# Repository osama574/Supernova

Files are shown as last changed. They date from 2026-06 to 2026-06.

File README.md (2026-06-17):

# Supernova ESP32 Smart Display

Supernova is a two-device ESP32 smart display project:

- `esp32-touchscreen`: LVGL touchscreen firmware for a diymore/LCDWiki 4.0 inch ESP32-32E display.
- `esp32-camera`: ESP32-CAM firmware for an AI-Thinker style ESP32-CAM with OV2640.
- `node-red`: Node-RED flow for simple MQTT motor control from a laptop dashboard.

The touchscreen is the main UI. It shows the Supernova boot animation, home dashboard, WiFi/settings, music, weather, clock, calendar, calculator, timer, and motor control. The camera firmware can join the same WiFi network, announce its IP to the display, and expose HTTP camera endpoints. Node-RED can send MQTT commands to move the two servos.

## Hardware

### Touchscreen firmware

Folder:

```text
esp32-touchscreen
```

Intended device:

- diymore / LCDWiki 4.0 inch ESP32-32E display
- 320 x 480 LCD, used in landscape as 480 x 320
- ST7796S display over SPI
- XPT2046 resistive touch over SPI
- LVGL 9 based UI

Connected extras used by the firmware:

- MAX98357A I2S audio amplifier and speaker
- microSD card for WAV music files
- WS2812/NeoPixel style LED ring
- Two servo motors for pan/tilt control

Hardware notes are in:

```text
esp32-touchscreen/docs/supernova_hardware_wiring.md
```

### Camera firmware

Folder:

```text
esp32-camera
```

Intended device:

- ESP32-CAM / AI-Thinker style module
- OV2640 camera
- PSRAM enabled board profile through PlatformIO `esp32cam`

The camera firmware provides:

- WiFi connection
- ESP-NOW credential receiving from the touchscreen
- HTTP status and camera endpoints
- Camera IP announcement back to the touchscreen

Useful endpoints after the ESP32-CAM is connected:

```text
http://CAMERA_IP/status
http://CAMERA_IP/capture
http://CAMERA_IP/stream
```

## Required Software

- VS Code with PlatformIO extension, or PlatformIO CLI
- Arduino framework through PlatformIO
- Node-RED already installed, if you want the laptop motor dashboard
- MQTT broker on the laptop, for example Mosquitto

## Configuration To Change

Before publishing or flashing your own copy, check these values.

### WiFi defaults

The GitHub copy uses placeholders so real WiFi credentials are not published.

Touchscreen:

```text
esp32-touchscreen/src/supernova_state.cpp
```

Camera:

```text
esp32-camera/src/main.cpp
```

Change:

```cpp
static const char * default_wifi_ssid = "CHANGE_ME_WIFI_SSID";
static const char * default_wifi_password = "CHANGE_ME_WIFI_PASSWORD";
```

The touchscreen also lets you connect to WiFi from the Settings UI. Successful WiFi credentials are saved in ESP32 flash. The ESP32-CAM can also receive WiFi credentials from the touchscreen over ESP-NOW.

If a device already has old saved credentials, use the touchscreen WiFi UI to connect to the new network, or erase flash from PlatformIO.

### MQTT broker IP

The ESP32 touchscreen must connect to the laptop's network IP address, not `localhost`.

Change this in:

```text
esp32-touchscreen/platformio.ini
```

Example:

```ini
-DSUPERNOVA_MQTT_HOST=\"172.20.10.2\"
```

If your laptop IP changes, update this value and upload the touchscreen firmware again.

Node-RED can use `127.0.0.1` if Node-RED and the MQTT broker are on the same laptop. If the broker is on another computer, change the broker in the Node-RED MQTT config node.

### Serial ports

The upload ports are examples and may be different on your computer:

- Touchscreen was tested on `COM6`
- ESP32-CAM was tested on `COM4`

Check Windows Device Manager or PlatformIO devices if your ports differ.

## Build And Upload: Touchscreen

From PowerShell:

```powershell
cd "C:\path\to\Supernova-ESP32-GitHub\esp32-touchscreen"
pio run -e esp32_32e_display
pio run -e esp32_32e_display -t upload --upload-port COM6
```

Serial monitor:

```powershell
pio device monitor -e esp32_32e_display --port COM6
```

If `pio` is not found but PlatformIO is installed by VS Code, use:

```powershell
& "$env:USERPROFILE\.platformio\penv\Scripts\pio.exe" run -e esp32_32e_display
```

## Build And Upload: ESP32-CAM

From PowerShell:

```powershell
cd "C:\path\to\Supernova-ESP32-GitHub\esp32-camera"
pio run -e esp32cam_ai_thinker
pio run -e esp32cam_ai_thinker -t upload --upload-port COM4
```

Serial monitor:

```powershell
pio device monitor -e esp32cam_ai_thinker --port COM4
```

If uploading fails, put the ESP32-CAM in bootloader mode. On many ESP32-CAM-MB adapter boards this means holding the `IO0` button, pressing reset, then starting upload. Release `IO0` after upload starts.

## Node-RED Motor Control

Flow file:

```text
node-red/nodered-supernova-motors-flow.json
```

Import:

1. Open Node-RED.
2. Menu -> Import.
3. Select the JSON file above or paste its contents.
4. Deploy.
5. Open the Node-RED dashboard.

The flow publishes servo commands to:

```text
supernova/motors/cmd
```

Payloads:

```text
up
down
left
right
```

The touchscreen publishes servo state to:

```text
supernova/motors/state
```

Example Mosquitto config:

```text
node-red/mosquitto-supernova.conf
```

For the ESP32 to reach the broker, Mosquitto must listen on the laptop network interface, not only on `localhost`. The included config uses:

```conf
listener 1883 0.0.0.0
allow_anonymous true
```

You may also need to allow port `1883` in Windows Firewall.

## Music Files

Put music files on the touchscreen SD card in:

```text
/music
```

The current firmware is focused on WAV playback. Use FAT32 for the SD card.

## Repository Layout

```text
Supernova-ESP32-GitHub/
  README.md
  .gitignore
  esp32-touchscreen/
    platformio.ini
    include/
    lib/
    scripts/
    src/
    docs/
  esp32-camera/
    platformio.ini
    src/
  node-red/
    nodered-supernova-motors-flow.json
    mosquitto-supernova.conf
```

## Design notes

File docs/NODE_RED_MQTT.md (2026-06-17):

# Node-RED And MQTT Motor Control

The Node-RED dashboard controls the same pan/tilt servos as the touchscreen Motor app.

## Files

Node-RED flow:

```text
node-red/nodered-supernova-motors-flow.json
```

Example Mosquitto config:

```text
node-red/mosquitto-supernova.conf
```

## MQTT Broker

The MQTT broker must run on the laptop or another computer reachable by the ESP32 touchscreen.

The included Mosquitto config:

```conf
listener 1883 0.0.0.0
allow_anonymous true
persistence false
log_type all
```

Why this matters:

- Node-RED can connect to `127.0.0.1` if it runs on the same laptop as the broker.
- The ESP32 cannot use `localhost`; it must use the laptop network IP address.

Example:

```text
Laptop MQTT broker IP: 172.20.10.2
MQTT port: 1883
```

Then set this in:

```text
esp32-touchscreen/platformio.ini
```

```ini
-DSUPERNOVA_MQTT_HOST=\"172.20.10.2\"
```

Rebuild and upload the touchscreen firmware after changing this value.

## Import Node-RED Flow

1. Open Node-RED.
2. Open the menu.
3. Choose Import.
4. Select `node-red/nodered-supernova-motors-flow.json`, or paste its contents.
5. Import the flow.
6. Deploy.
7. Open the Node-RED dashboard.

The flow contains:

- Up button
- Down button
- Left button
- Right button
- MQTT output node
- MQTT input node for servo state
- Text display for the latest servo state

## MQTT Topics

Command topic:

```text
supernova/motors/cmd
```

Accepted payloads:

```text
up
down
left
right
```

State topic:

```text
supernova/motors/state
```

Example state payload:

```json
{"pan":135,"tilt":135,"source":"status"}
```

## Test Broker From Windows

Check local broker:

```powershell
Test-NetConnection 127.0.0.1 -Port 1883
```

Check broker on laptop network IP:

```powershell
Test-NetConnection 172.20.10.2 -Port 1883
```

Both should show:

```text
TcpTestSucceeded : True
```

If `127.0.0.1` works but the laptop IP does not, the broker is only listening locally or Windows Firewall is blocking port 1883.

## Windows Firewall

If needed, allow MQTT inbound traffic:

```powershell
New-NetFirewallRule -DisplayName "MQTT 1883" -Direction Inbound -Protocol TCP -LocalPort 1883 -Action Allow
```

Run PowerShell as Administrator for this command.

## Expected ESP32 Display Status

Open the Motor app on the touchscreen. It should show:

```text
Broker: YOUR_BROKER_IP
MQTT: online
```

If it shows `MQTT: retry`, check:

- Touchscreen WiFi is connected.
- Laptop and touchscreen are on the same network.
- MQTT broker is running.
- `SUPERNOVA_MQTT_HOST` is the laptop IP.
- Windows Firewall allows port 1883.

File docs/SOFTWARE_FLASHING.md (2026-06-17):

# Software Setup And Flashing

This repository contains two separate PlatformIO projects.

| Folder | Device | PlatformIO Environment |
| --- | --- | --- |
| `esp32-touchscreen` | diymore/LCDWiki 4.0 inch ESP32-32E touchscreen | `esp32_32e_display` |
| `esp32-camera` | ESP32-CAM AI-Thinker style board | `esp32cam_ai_thinker` |

## Install Requirements

Required:

- VS Code
- PlatformIO extension for VS Code, or PlatformIO CLI
- USB cable for the touchscreen
- USB programmer/adapter for the ESP32-CAM

If `pio` is not available in PowerShell, use the VS Code PlatformIO terminal or this full path:

```powershell
& "$env:USERPROFILE\.platformio\penv\Scripts\pio.exe"
```

## Configure WiFi

The GitHub copy uses placeholders.

Touchscreen file:

```text
esp32-touchscreen/src/supernova_state.cpp
```

Camera file:

```text
esp32-camera/src/main.cpp
```

Change:

```cpp
static const char * default_wifi_ssid = "CHANGE_ME_WIFI_SSID";
static const char * default_wifi_password = "CHANGE_ME_WIFI_PASSWORD";
```

The touchscreen can also change WiFi from the Settings app. Successful WiFi credentials are saved in ESP32 flash.

## Configure MQTT Broker IP

The touchscreen connects directly to the MQTT broker. If the broker runs on your laptop, use the laptop IP address on the same WiFi network.

Edit:

```text
esp32-touchscreen/platformio.ini
```

Change:

```ini
-DSUPERNOVA_MQTT_HOST=\"CHANGE_ME_BROKER_IP\"
```

Example:

```ini
-DSUPERNOVA_MQTT_HOST=\"172.20.10.2\"
```

Do not use `localhost` for the ESP32. On the ESP32, `localhost` means the ESP32 itself, not the laptop.

## Build Touchscreen Firmware

PowerShell:

```powershell
cd "C:\path\to\Supernova\esp32-touchscreen"
pio run -e esp32_32e_display
```

If `pio` is not found:

```powershell
cd "C:\path\to\Supernova\esp32-touchscreen"
& "$env:USERPROFILE\.platformio\penv\Scripts\pio.exe" run -e esp32_32e_display
```

Expected result:

```text
[SUCCESS]
```

## Upload Touchscreen Firmware

Find the COM port in Windows Device Manager or PlatformIO devices. Example port:

```text
COM6
```

Upload:

```powershell
cd "C:\path\to\Supernova\esp32-touchscreen"
pio run -e esp32_32e_display -t upload --upload-port COM6
```

Serial monitor:

```powershell
pio device monitor -e esp32_32e_display --port COM6
```

Expected after boot:

- Supernova boot animation
- Home dashboard
- Touch works in landscape

## Build ESP32-CAM Firmware

PowerShell:

```powershell
cd "C:\path\to\Supernova\esp32-camera"
pio run -e esp32cam_ai_thinker
```

Expected result:

```text
[SUCCESS]
```

## Upload ESP32-CAM Firmware

Example port:

```text
COM4
```

Upload:

```powershell
cd "C:\path\to\Supernova\esp32-camera"
pio run -e esp32cam_ai_thinker -t upload --upload-port COM4
```

Serial monitor:

```powershell
pio device monitor -e esp32cam_ai_thinker --port COM4
```

ESP32-CAM bootloader mode:

- If upload does not start, hold `IO0`.
- Press `RST`.
- Start upload.
- Release `IO0` after upload begins.

Some ESP32-CAM-MB boards have an `IO0` button instead of requiring a jumper.

## Erase Flash

Erase flash if old WiFi credentials or settings are stuck:

Touchscreen:

```powershell
cd "C:\path\to\Supernova\esp32-touchscreen"
pio run -e esp32_32e_display -t erase --upload-port COM6
```

Camera:

```powershell
cd "C:\path\to\Supernova\esp32-camera"
pio run -e esp32cam_ai_thinker -t erase --upload-port COM4
```

Then upload firmware again.

## What The Firmware Does

Touchscreen firmware:

- Initializes ST7796S LCD in landscape
- Initializes XPT2046 touch
- Runs LVGL 9 UI
- Shows Supernova boot animation
- Provides dashboard apps
- Saves theme/language/brightness/WiFi settings
- Reads WAV music from SD card
- Controls two servo motors
- Controls LED ring
- Receives camera IP state
- Subscribes to MQTT motor commands

Camera firmware:

- Initializes OV2640 camera
- Connects to WiFi
- Receives WiFi credentials over ESP-NOW
- Starts HTTP camera server
- Announces IP address to touchscreen

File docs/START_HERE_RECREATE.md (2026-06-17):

# Start Here: Recreate The Supernova Project

This document is the handoff guide for rebuilding Supernova from the repository with no extra help. Follow the sections in order.

## What You Are Building

Supernova is a smart display system made from two ESP32 devices:

1. Main display controller
   - diymore/LCDWiki 4.0 inch ESP32-32E touchscreen display
   - Runs the LVGL user interface
   - Controls music, settings, WiFi, weather, clock, calendar, timer, calculator, servos, LED ring, and MQTT motor commands

2. Camera controller
   - ESP32-CAM AI-Thinker style board with OV2640 camera
   - Joins the same WiFi network
   - Provides HTTP camera endpoints
   - Announces its IP address to the touchscreen

There is also a Node-RED dashboard flow for controlling the servo motors over MQTT from a laptop.

## Repository Map

```text
Supernova/
  README.md
  docs/
    START_HERE_RECREATE.md
    BOM.md
    3D_PRINTING_AND_ASSEMBLY.md
    WIRING.md
    SOFTWARE_FLASHING.md
    NODE_RED_MQTT.md
    OPERATION_TEST_PLAN.md
    TROUBLESHOOTING.md
  3D-Model/
    pantilt_floor_nolegs.stl
    pantilt_leg.stl
    pantilt_screenpanel.stl
  esp32-touchscreen/
    platformio.ini
    src/
    include/
    scripts/
  esp32-camera/
    platformio.ini
    src/
  node-red/
    nodered-supernova-motors-flow.json
    mosquitto-supernova.conf
```

## Build Order

1. Read `docs/BOM.md` and confirm all parts are available.
2. Print the case parts from `3D-Model/`; follow `docs/3D_PRINTING_AND_ASSEMBLY.md`.
3. Wire the electronics according to `docs/WIRING.md`.
4. Edit WiFi and MQTT settings as described in `docs/SOFTWARE_FLASHING.md`.
5. Build and upload the touchscreen firmware.
6. Build and upload the ESP32-CAM firmware.
7. Import the Node-RED flow using `docs/NODE_RED_MQTT.md`.
8. Run the acceptance test in `docs/OPERATION_TEST_PLAN.md`.
9. If something fails, use `docs/TROUBLESHOOTING.md`.

## Expected Result

After everything is working:

- The touchscreen boots into the Supernova animation and home dashboard.
- Touch works in landscape orientation.
- Settings can connect/disconnect WiFi.
- Music lists WAV files from the SD card.
- The Motor app moves pan/tilt servos from touch buttons.
- The Motor app shows the ESP32-CAM IP when the camera is available.
- Node-RED can move the same motors by publishing MQTT commands.
- The ESP32-CAM exposes camera endpoints on the local network.

## Important Safety Rules

- Do not power the 20 kg servos from the ESP32 display board.
- Do not power the LED ring from the ESP32 display board.
- Use a separate high-current 5V supply for LEDs.
- Use a separate high-current servo supply/BEC for servos.
- Connect all grounds together: ESP32 GND, LED GND, servo supply GND, and audio GND.
- Check polarity before powering the system.
- If a servo moves randomly, remove servo power first, then debug wiring and ground.

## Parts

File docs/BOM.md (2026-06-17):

# Bill Of Materials

This is the hardware needed to recreate the current Supernova prototype.

## Required Electronics

| Qty | Part | Purpose | Notes |
| --- | --- | --- | --- |
| 1 | diymore/LCDWiki 4.0 inch ESP32-32E touchscreen display | Main UI controller | 320 x 480 display, used in landscape as 480 x 320 |
| 1 | ESP32-CAM AI-Thinker style board with OV2640 | Camera controller | Tested with ESP32-CAM-MB style USB programmer |
| 2 | RDS3218 20 kg 270 degree servos | Pan/tilt movement | Needs external servo power |
| 1 | 109 pixel WS2812/NeoPixel compatible LED ring | Addressable LED effect | Needs external 5V power |
| 1 | microSD card | Music storage | FAT32, `/music` folder |
| 1 | Speaker or speaker module supported by the display board | Audio output | Current firmware uses ESP32 DAC output on GPIO26 |
| 1 | Laptop | PlatformIO upload, Node-RED, MQTT broker | Windows commands are documented |

## Optional Electronics

| Qty | Part | Purpose | Notes |
| --- | --- | --- | --- |
| 1 or 2 | MAX98357A amplifier modules | External audio amplifier option | Current firmware does not drive external I2S MAX98357A. Code changes are needed for this option. |
| 1 | PCA9685 servo driver | Cleaner multi-servo control | Recommended future upgrade if more PWM outputs are needed. |

## Power Supplies

| Supply | Recommended Rating | Used For |
| --- | --- | --- |
| USB-C or 5V supply for touchscreen | Stable 5V, at least 1A | ESP32 display board |
| LED supply | 5V, up to 8A for full brightness | 109 LED ring |
| Servo supply/BEC | Match servo rating, several amps per servo | Two high-current servos |

The LED and servo supplies can draw far more current than the ESP32 board can provide. Keep power separate, but connect grounds together.

## Mechanical Parts

Print these files from the repository:

| File | Purpose |
| --- | --- |
| `3D-Model/pantilt_floor_nolegs.stl` | Base/floor part |
| `3D-Model/pantilt_leg.stl` | Leg/support part |
| `3D-Model/pantilt_screenpanel.stl` | Screen panel mount |

See `docs/3D_PRINTING_AND_ASSEMBLY.md` for print and assembly steps.

## Tools

- 3D printer
- Slicer software
- Small screwdrivers
- Soldering iron or reliable Dupont/JST wiring
- Multimeter
- USB cables for both ESP32 devices
- Heat shrink or insulation tape
- Computer with VS Code and PlatformIO

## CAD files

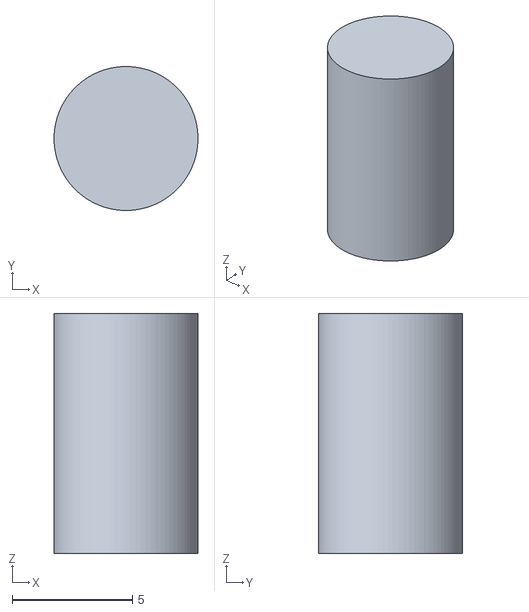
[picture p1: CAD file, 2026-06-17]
3D-Model/pantilt_leg.stl
6.00 x 6.00 x 10.0

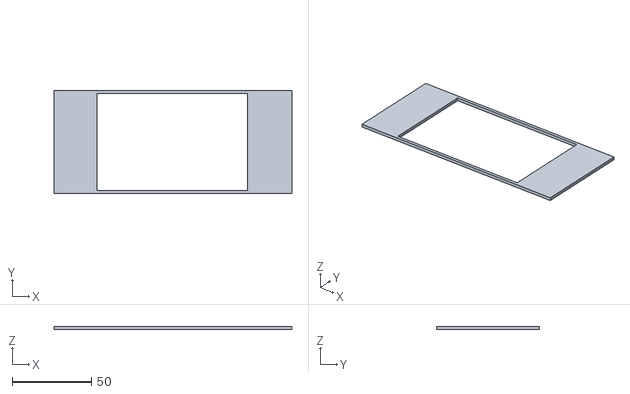
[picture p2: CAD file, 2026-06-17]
3D-Model/pantilt_screenpanel.stl
150.0 x 65.0 x 2.00

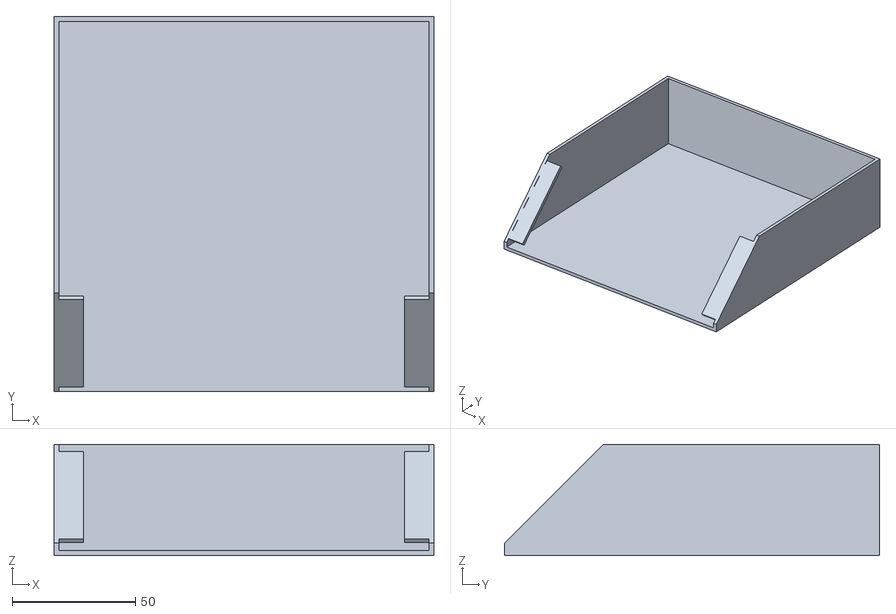
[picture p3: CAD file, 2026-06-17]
3D-Model/pantilt_floor_nolegs.stl
154.0 x 152.0 x 45.0

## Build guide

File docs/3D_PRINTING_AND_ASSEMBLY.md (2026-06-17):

# 3D Printing And Physical Assembly

The case files are in:

```text
3D-Model/
```

Files:

```text
3D-Model/pantilt_floor_nolegs.stl
3D-Model/pantilt_leg.stl
3D-Model/pantilt_screenpanel.stl
```

## Recommended Print Settings

These are safe starting settings for a normal FDM printer:

| Setting | Recommended Value |
| --- | --- |
| Material | PLA+ or PETG |
| Layer height | 0.20 mm |
| Walls/perimeters | 3 or 4 |
| Infill | 20% to 35% |
| Top/bottom layers | 4 or more |
| Supports | Enable if your slicer shows unsupported overhangs |
| Brim | Recommended for tall or narrow parts |

PETG is better if the device may sit in a warm place. PLA is easier for first prints.

## Print Checklist

1. Open the three STL files in your slicer.
2. Check that each model is flat on the build plate.
3. Slice with the settings above.
4. Print one part first and test fit before printing replacements.
5. Remove supports carefully.
6. Clean screw holes and cable paths with a small tool if needed.

## Mechanical Assembly Order

1. Place the base part `pantilt_floor_nolegs.stl` on the table.
2. Attach the leg/support part `pantilt_leg.stl` to the base.
3. Attach the screen panel part `pantilt_screenpanel.stl` to the support.
4. Test fit the touchscreen display before tightening everything.
5. Route wires so they do not rub against moving servo parts.
6. Mount servos only after checking their center position in software.

## Servo Centering Before Final Assembly

Before physically attaching arms/brackets to the servos:

1. Flash the touchscreen firmware.
2. Power the touchscreen and servo power supply.
3. Open the Motor app.
4. Let both servos move to the firmware center position.
5. Attach the mechanical servo horns/brackets while the servos are centered.

The firmware starts the servos at:

```text
Pan 135 degrees
Tilt 135 degrees
```

The software limit range is:

```text
5 degrees to 265 degrees
```

## Cable Routing

- Keep servo power wires away from the touch/display ribbon cables.
- Use strain relief for servo and LED wires.
- Do not leave exposed 5V or servo supply wires near the ESP32 pins.
- Leave access to the touchscreen USB-C port for flashing.
- Leave access to the ESP32-CAM USB/programmer port for flashing.

## Final Mechanical Check

Before powering everything together:

- Display is firmly mounted.
- Servo arms can move without hitting the case.
- LED ring wires cannot be pulled loose.
- Servo supply polarity is correct.
- All grounds are connected together.
- No loose wires can short against the display board.

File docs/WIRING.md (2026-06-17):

# Wiring Guide

This guide documents the current firmware pin mapping and safe wiring for the Supernova prototype.

## System Diagram

```mermaid
flowchart LR
    Laptop["Laptop<br/>VS Code, PlatformIO, Node-RED, MQTT broker"]
    Touch["ESP32 Touchscreen<br/>Main Supernova UI"]
    Cam["ESP32-CAM<br/>Camera HTTP server"]
    SD["microSD card<br/>/music WAV files"]
    Servos["Two 20 kg servos<br/>external servo power"]
    LED["109 pixel LED ring<br/>external 5V power"]
    Speaker["Speaker output<br/>ESP32 DAC GPIO26 path"]

    Laptop -- USB flash / MQTT --> Touch
    Laptop -- USB flash / browser --> Cam
    Touch -- ESP-NOW credentials / announce --> Cam
    Touch -- SPI --> SD
    Touch -- PWM --> Servos
    Touch -- data GPIO21 --> LED
    Touch -- audio --> Speaker
```

## Touchscreen Board Pins Already Used Internally

These are fixed by the diymore/LCDWiki ESP32-32E display board and the firmware.

| Function | ESP32 GPIO |
| --- | --- |
| LCD CS | GPIO15 |
| LCD DC | GPIO2 |
| LCD SCLK | GPIO14 |
| LCD MOSI | GPIO13 |
| LCD MISO | GPIO12 |
| LCD backlight | GPIO27 |
| Touch CS | GPIO33 |
| Touch IRQ | GPIO36 |
| microSD CS | GPIO5 |
| microSD SCLK | GPIO18 |
| microSD MOSI | GPIO23 |
| microSD MISO | GPIO19 |

Do not reuse these pins for extra devices.

## Current External Pin Mapping

These are defined in:

```text
esp32-touchscreen/src/supernova_devices.h
esp32-touchscreen/src/board_pins.h
```

| Device | Signal | ESP32 GPIO | Notes |
| --- | --- | --- | --- |
| LED ring | Data in | GPIO21 | Use 330 ohm resistor in series if possible |
| Servo pan | PWM signal | GPIO25 | External servo power required |
| Servo tilt | PWM signal | GPIO32 | External servo power required |
| Audio/speaker | DAC audio | GPIO26 | Current firmware uses ESP32 built-in DAC output |
| LCD backlight | PWM brightness | GPIO27 | Board backlight control |

## Servo Wiring

The RDS3218 servos must be powered from a separate servo supply/BEC. Do not power them from the ESP32 board.

| Servo Wire | Connect To |
| --- | --- |
| Pan servo signal | ESP32 GPIO25 |
| Tilt servo signal | ESP32 GPIO32 |
| Servo V+ | External servo supply positive |
| Servo GND | External servo supply ground and ESP32 GND |

Rules:

- Connect ESP32 GND to servo supply GND.
- Use a high-current supply. These servos can pull large current spikes.
- If servos vibrate or move randomly, check ground, power supply current, and signal wiring.
- Keep servo wires away from display/touch ribbon cables.

## LED Ring Wiring

The LED ring is a 5V addressable WS2812/NeoPixel style ring.

| LED Ring Pin | Connect To |
| --- | --- |
| 5V | External 5V LED supply |
| GND | External 5V supply ground and ESP32 GND |
| DIN | ESP32 GPIO21 |

Recommended protection:

- 330 ohm resistor between GPIO21 and DIN.
- 1000 uF capacitor across LED 5V and GND near the ring.
- Logic level shifter if LED data is unreliable.

Power warning:

- 109 LEDs can draw about 6.5A at full white.
- Use a strong 5V supply if high brightness is enabled.
- Current firmware keeps LED brightness low for safety.

## Audio Wiring

The current firmware plays WAV audio through the ESP32 built-in DAC path on GPIO26. This matches the display board speaker/audio interface used in the prototype.

Important:

- The current firmware does not output external I2S BCLK/LRCLK/DIN for a MAX98357A module.
- If you want to use MAX98357A, change the audio driver code first.
- Do not connect speakers directly to random ESP32 GPIO pins.

## SD Card

Use a microSD card formatted as FAT32.

Music folder:

```text
/music
```

Supported music files:

- `.wav`
- PCM format
- 8-bit or 16-bit
- mono or stereo
- up to 120 detected songs

MP3 files are not currently played by the firmware.

## ESP32-CAM Wiring

The ESP32-CAM is a separate board. It does not need signal wires to the touchscreen for normal operation.

Connections:

- USB programmer/adapter for flashing and power during development.
- Same WiFi network as the touchscreen after setup.

Communication:

- Touchscreen sends WiFi credentials over ESP-NOW.
- Camera announces its IP address back to the touchscreen.
- Camera serves HTTP endpoints over WiFi.

## Shared Ground Rule

All supplies must share ground:

```text
ESP32 display GND
LED power supply GND
Servo power supply GND
Audio/speaker GND if external
```

Without a shared ground, servo control and LED data will be unreliable.

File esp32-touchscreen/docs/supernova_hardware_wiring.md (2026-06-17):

# Supernova hardware wiring

Target controller: diymore/LCDWiki 4.0 inch ESP32-32E touchscreen display.

Known pins already used by the display board:

| Function | ESP32 GPIO |
| --- | --- |
| LCD CS | GPIO15 |
| LCD DC | GPIO2 |
| LCD SCLK | GPIO14 |
| LCD MOSI | GPIO13 |
| LCD MISO | GPIO12 |
| LCD backlight | GPIO27 |
| Touch CS | GPIO33 |
| Touch IRQ | GPIO36 |
| microSD CS | GPIO5 |
| microSD SCLK | GPIO18 |
| microSD MOSI | GPIO23 |
| microSD MISO | GPIO19 |

## Proposed extra pins

| Device | Signal | ESP32 GPIO |
| --- | --- | --- |
| MAX98357A amp pair | I2S BCLK | GPIO25 |
| MAX98357A amp pair | I2S LRC / LRCLK | GPIO32 |
| MAX98357A amp pair | I2S DIN | GPIO26 |
| 109 LED ring | Data in | GPIO21 |
| Servo 1 | PWM signal | TBD |
| Servo 2 | PWM signal | TBD |

## Audio

Use two MAX98357A amplifier boards for two speakers. Do not connect speakers directly to the ESP32.

For both MAX98357A boards:

| MAX98357A pin | Connect to |
| --- | --- |
| VIN | 5V external supply |
| GND | Common ground with ESP32 |
| BCLK | ESP32 GPIO25 |
| LRC | ESP32 GPIO32 |
| DIN | ESP32 GPIO26 |
| Speaker + / - | One 8 ohm speaker |

Because the MAX98357A boards are mono, the clean setup is one amplifier per speaker. Feed both amplifiers the same I2S signals for dual-mono audio. Avoid connecting two 8 ohm speakers in parallel to one amp because that becomes 4 ohm and can overload the module.

## LED ring

The 109-pixel 5V addressable LED ring needs a separate 5V supply.

| LED ring pin | Connect to |
| --- | --- |
| 5V | External 5V supply |
| GND | External supply ground and ESP32 GND |
| DIN | ESP32 GPIO21 through 330 ohm resistor |

Recommended protection:

- 1000 uF capacitor across LED 5V and GND near the ring.
- Logic level shifter from ESP32 3.3V data to 5V data if the ring is unreliable.
- Power budget: 109 LEDs can draw about 6.5A at full white. Use a 5V supply rated around 8A or more if you want full brightness.

## Servos

The RDS3218 servos must use a separate servo power supply/BEC. Do not power them from the ESP32 board.

Do not use GPIO18 or GPIO19 for servos on this display board. Those pins are used by the on-board microSD card, so using them for servo PWM will break SD music playback. A clean future option is an external PCA9685 servo driver on the board's I2C pins.

| Servo wire | Connect to |
| --- | --- |
| Servo 1 signal | Future servo driver channel 1 |
| Servo 2 signal | Future servo driver channel 2 |
| Servo V+ | External servo supply, usually 6V to 8.4V depending on your servo rating |
| Servo GND | External supply ground and ESP32 GND |

Use a high-current supply. Two 20 kg servos can pull large current spikes, so plan for several amps per servo.

## Shared ground rule

All external supplies must share ground with the ESP32 touchscreen:

ESP32 GND, LED power GND, servo power GND, and audio amp GND must be connected together.

## ESP32-CAM later

The touchscreen will store WiFi settings. Later, the ESP32-CAM can either:

- join the same WiFi using the same SSID/password, or
- boot into a temporary setup mode where the touchscreen sends WiFi credentials over a local HTTP/BLE/provisioning link.

The current firmware contains only the camera UI placeholder and servo control overlay stubs.

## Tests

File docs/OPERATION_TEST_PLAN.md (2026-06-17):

# Operation And Acceptance Test Plan

Use this checklist after assembly and flashing. Do not skip steps; each step proves one part of the system.

## 1. First Power-On

1. Connect only the touchscreen by USB.
2. Power on.
3. Confirm the boot animation appears.
4. Confirm the home dashboard appears.
5. Confirm the screen is landscape.

Pass condition:

```text
Supernova boot animation -> home dashboard
```

## 2. Touch Test

1. Tap Settings.
2. Tap back.
3. Tap Motor app.
4. Tap each arrow button.

Pass condition:

- Taps select the intended buttons.
- Left side does not press right side.
- Up/down are not inverted.

## 3. WiFi Test

1. Open Settings.
2. Open WiFi setup.
3. Enter SSID and password.
4. Tap Connect.
5. Return to home.

Pass condition:

- Top bar shows connected WiFi icon.
- Clock eventually updates from internet.
- Weather can load.

## 4. SD Music Test

Prepare SD card:

```text
FAT32
/music
/music/example.wav
```

Supported WAV:

- PCM
- 8-bit or 16-bit
- mono or stereo

Test:

1. Insert SD card.
2. Boot touchscreen.
3. Open Music app.
4. Confirm songs appear.
5. Play one song.

Pass condition:

- Song list appears.
- Audio plays.
- UI stays responsive.

## 5. Servo Touchscreen Test

1. Power servo supply.
2. Confirm servo GND and ESP32 GND are connected.
3. Open Motor app.
4. Press left, right, up, and down.

Pass condition:

- Pan servo moves left/right.
- Tilt servo moves up/down.
- Each tap moves about 2 degrees.
- Holding a button repeats movement.
- No random movement when buttons are not pressed.

## 6. LED Ring Test

1. Connect LED ring 5V supply.
2. Connect LED GND to ESP32 GND.
3. Connect DIN to GPIO21.
4. Open Settings.
5. Change LED mode.

Pass condition:

- LED mode changes according to firmware setting.
- No ESP32 reset when LEDs turn on.

## 7. ESP32-CAM Test

1. Flash ESP32-CAM firmware.
2. Open serial monitor.
3. Wait for WiFi connection.
4. Note the camera IP.
5. Open browser:

```text
http://CAMERA_IP/status
http://CAMERA_IP/capture
http://CAMERA_IP/stream
```

Pass condition:

- `/status` returns JSON.
- `/capture` returns an image.
- `/stream` returns camera stream.
- Motor app on touchscreen shows CAM IP.

## 8. Node-RED MQTT Motor Test

1. Start MQTT broker.
2. Deploy Node-RED flow.
3. Confirm Node-RED MQTT node says connected.
4. Open Node-RED dashboard.
5. Press each motor button.

Pass condition:

- Servos move from Node-RED buttons.
- Touchscreen Motor app shows `MQTT: online`.
- State updates appear on topic `supernova/motors/state`.

## 9. Final Full-System Test

With everything connected:

1. Power touchscreen.
2. Power servo supply.
3. Power LED supply.
4. Start MQTT broker.
5. Start Node-RED.
6. Power ESP32-CAM.
7. Verify home dashboard.
8. Verify WiFi icon.
9. Verify music list.
10. Verify motor control from touchscreen.
11. Verify motor control from Node-RED.
12. Verify camera IP is visible.

The project is accepted only when all checks pass.

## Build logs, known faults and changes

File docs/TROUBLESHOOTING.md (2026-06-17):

# Troubleshooting

Use this guide when the system does not behave as expected.

## PlatformIO Cannot Find `pio`

Use the full PlatformIO path:

```powershell
& "$env:USERPROFILE\.platformio\penv\Scripts\pio.exe" run
```

Or open the project folder in VS Code and use the PlatformIO extension.

## Upload Fails

Check:

- Correct COM port.
- USB cable supports data.
- No serial monitor is already using the same COM port.
- Correct PlatformIO environment.

Touchscreen:

```powershell
pio run -e esp32_32e_display -t upload --upload-port COM6
```

ESP32-CAM:

```powershell
pio run -e esp32cam_ai_thinker -t upload --upload-port COM4
```

For ESP32-CAM, hold `IO0`, press `RST`, start upload, then release `IO0` after upload begins.

## Touchscreen Stays White Or Blank

Possible causes:

- Wrong display initialization.
- Firmware did not boot.
- Power problem.
- Wrong project uploaded to the board.

Actions:

1. Open serial monitor at 115200 baud.
2. Confirm boot logs appear.
3. Rebuild and upload `esp32-touchscreen`.
4. Confirm the target environment is `esp32_32e_display`.
5. Check USB power stability.

## Touch Coordinates Are Wrong

Symptoms:

- Pressing right triggers left.
- Pressing top triggers bottom.
- Buttons respond offset from finger.

Actions:

1. Confirm the firmware is the current landscape version.
2. Check touch logs in serial monitor.
3. Adjust mapping in:

```text
esp32-touchscreen/src/main.cpp
```

Touch mapping is inside `lvgl_touch_read_cb`.

## Songs Do Not Show

Check SD card:

- Format: FAT32
- Folder: `/music`
- Files: `.wav`
- WAV format: PCM, 8-bit or 16-bit, mono or stereo

The firmware ignores MP3 files.

The firmware detects up to 120 WAV files.

If the card was recently reformatted:

1. Create folder `music` at the SD card root.
2. Put WAV files directly inside it.
3. Reinsert card.
4. Restart device.
5. Open Music app.

## Song Plays Slow Or Distorted

Possible causes:

- Unsupported WAV encoding.
- Very high sample rate.
- Weak speaker/amplifier wiring.
- Power noise.

Recommended test file:

- WAV PCM
- 16-bit
- 44100 Hz or 22050 Hz
- mono or stereo

## MQTT Node-RED Says Connecting

This means Node-RED cannot connect to the MQTT broker.

Check broker locally:

```powershell
Test-NetConnection 127.0.0.1 -Port 1883
```

Check broker from laptop IP:

```powershell
Test-NetConnection YOUR_LAPTOP_IP -Port 1883
```

Fixes:

- Start Mosquitto.
- Use `node-red/mosquitto-supernova.conf`.
- Allow port 1883 in Windows Firewall.
- In Node-RED, set broker to `127.0.0.1` if broker and Node-RED are on the same laptop.

## ESP32 Shows `MQTT: retry`

This means the touchscreen cannot connect to the MQTT broker.

Check:

- Touchscreen WiFi connected.
- Laptop and touchscreen are on the same WiFi/hotspot.
- `SUPERNOVA_MQTT_HOST` is the laptop network IP, not `localhost`.
- MQTT broker listens on `0.0.0.0:1883`.
- Firewall allows incoming TCP 1883.

After changing `SUPERNOVA_MQTT_HOST`, rebuild and upload the touchscreen firmware.

## Servos Do Not Move

Check:

- Servo supply is on.
- Servo supply voltage matches servo rating.
- Servo GND is connected to ESP32 GND.
- Pan signal is GPIO25.
- Tilt signal is GPIO32.
- You are in the Motor app.

If testing from Node-RED:

- MQTT broker connected.
- Topic is `supernova/motors/cmd`.
- Payload is `up`, `down`, `left`, or `right`.

## Servos Move Randomly Or Vibrate

Common causes:

- Weak servo power supply.
- No shared ground.
- Loose signal wire.
- Servo horn mechanically blocked.
- Signal wire near noisy power wires.

Actions:

1. Disconnect servo power.
2. Confirm wiring.
3. Connect grounds together.
4. Test one servo at a time.
5. Keep servo power wires away from signal wires.

## ESP32-CAM Shows No Camera Frame

Common causes:

- Camera ribbon cable not seated.
- Wrong camera board model.
- Weak power.
- ESP32-CAM not in correct firmware.
- OV2640 module issue.

Actions:

1. Reseat the camera ribbon cable.
2. Use stable 5V power.
3. Reflash `esp32-camera`.
4. Open serial monitor.
5. Check:

```text
http://CAMERA_IP/status
http://CAMERA_IP/capture
```

If `/status` works but `/capture` fails, the WiFi server is alive but the sensor/camera path is failing.

## ESP32-CAM IP Changes

The IP address is assigned by the router/hotspot DHCP server. It can change.

Options:

- Check serial monitor during development.
- Look in the touchscreen Motor app, which shows the camera IP when the camera announces itself.
- Reserve a DHCP address in the router/hotspot if available.

## Weather Or Clock Does Not Update

Check:

- WiFi connected.
- Internet is available.
- Time sync may take a little while after boot.
- Weather needs internet access to call the Open-Meteo API.

If WiFi disconnects after time sync, the clock keeps running from the ESP32 runtime clock.

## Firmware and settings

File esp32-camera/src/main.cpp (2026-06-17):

#include <Arduino.h>
#include <Preferences.h>
#include <WiFi.h>
#include <esp_camera.h>
#include <esp_heap_caps.h>
#include <esp_http_server.h>
#include <esp_now.h>
#include <esp_wifi.h>
#include <img_converters.h>
#include <Wire.h>

/* ESP32-CAM-MB / AI-Thinker pinout, matching CBAA0046-044_UK manual. */
#define PWDN_GPIO_NUM 32
#define RESET_GPIO_NUM -1
#define XCLK_GPIO_NUM 0
#define SIOD_GPIO_NUM 26
#define SIOC_GPIO_NUM 27
#define Y9_GPIO_NUM 35
#define Y8_GPIO_NUM 34
#define Y7_GPIO_NUM 39
#define Y6_GPIO_NUM 36
#define Y5_GPIO_NUM 21
#define Y4_GPIO_NUM 19
#define Y3_GPIO_NUM 18
#define Y2_GPIO_NUM 5
#define VSYNC_GPIO_NUM 25
#define HREF_GPIO_NUM 23
#define PCLK_GPIO_NUM 22
#define FLASH_GPIO_NUM 4

typedef struct __attribute__((packed)) {
    uint32_t magic;
    uint8_t version;
    uint8_t type;
    uint8_t channel;
    uint8_t reserved;
    char ssid[33];
    char password[65];
    char ip[16];
    uint16_t port;
} supernova_camera_packet_t;

static const uint32_t camera_packet_magic = 0x434D5653UL;
static const uint8_t camera_packet_version = 1;
static const uint8_t camera_packet_credentials = 1;
static const uint8_t camera_packet_announce = 2;
static const uint8_t broadcast_mac[6] = {0xff, 0xff, 0xff, 0xff, 0xff, 0xff};
static const char * old_default_wifi_ssid = "CHANGE_ME_OLD_SSID";
static const char * default_wifi_ssid = "CHANGE_ME_WIFI_SSID";
static const char * default_wifi_password = "CHANGE_ME_WIFI_PASSWORD";
static const uint8_t current_wifi_revision = 2;
static const uint16_t preview_width = 260;
static const uint16_t preview_height = 150;
static const uint16_t camera_capture_width = 160;
static const uint16_t camera_capture_height = 120;

static Preferences prefs;
static httpd_handle_t camera_httpd = NULL;
static char saved_ssid[33] = "";
static char saved_password[65] = "";
static volatile bool pending_wifi_connect = false;
static volatile bool pending_credentials_save = false;
static bool espnow_ready = false;
static bool camera_initialized = false;
static uint8_t listen_channel = 1;
static uint32_t last_channel_hop_ms = 0;
static uint32_t last_wifi_attempt_ms = 0;
static uint32_t last_camera_init_attempt_ms = 0;
static uint32_t last_announce_ms = 0;
static uint32_t last_loop_log_ms = 0;
static uint32_t last_sccb_probe_ms = 0;
static uint16_t * preview_decode_buffer = NULL;
static uint16_t * preview_output_buffer = NULL;

static void save_credentials(const char * ssid, const char * password)
{
    if(ssid != NULL && strcmp(saved_ssid, ssid) == 0 && WiFi.status() == WL_CONNECTED) {
        return;
    }

    strncpy(saved_ssid, ssid == NULL ? "" : ssid, sizeof(saved_ssid) - 1);
    saved_ssid[sizeof(saved_ssid) - 1] = '\0';
    strncpy(saved_password, password == NULL ? "" : password, sizeof(saved_password) - 1);
    saved_password[sizeof(saved_password) - 1] = '\0';
    pending_credentials_save = true;
    pending_wifi_connect = saved_ssid[0] != '\0';
    Serial.printf("Received WiFi credentials for SSID: %s\n", saved_ssid);
}

static void save_credentials_to_flash(void)
{
    if(!pending_credentials_save) {
        return;
    }
    pending_credentials_save = false;
    if(prefs.begin("supernova", false)) {
        prefs.putString("wifi_ssid", saved_ssid);
        prefs.putString("wifi_pass", saved_password);
        prefs.putUChar("wifi_rev", current_wifi_revision);
        prefs.end();
    }
}

static void load_credentials(void)
{
    saved_ssid[0] = '\0';
    saved_password[0] = '\0';
    if(prefs.begin("supernova", true)) {
        String ssid = prefs.getString("wifi_ssid", "");
        String password = prefs.getString("wifi_pass", "");
        uint8_t revision = prefs.getUChar("wifi_rev", 0);
        prefs.end();
        if(ssid.length() > 0 && ssid != old_default_wifi_ssid && revision == current_wifi_revision) {
            ssid.toCharArray(saved_ssid, sizeof(saved_ssid));
            password.toCharArray(saved_password, sizeof(saved_password));
        }
    }

    if(saved_ssid[0] == '\0') {
        strncpy(saved_ssid, default_wifi_ssid, sizeof(saved_ssid) - 1);
        saved_ssid[sizeof(saved_ssid) - 1] = '\0';
        strncpy(saved_password, default_wifi_password, sizeof(saved_password) - 1);
        saved_password[sizeof(saved_password) - 1] = '\0';
        Serial.printf("Using default WiFi credentials for SSID: %s\n", saved_ssid);
    }
}

static void espnow_receive_cb(const uint8_t * mac, const uint8_t * data, int len)
{
    (void)mac;
    if(data == NULL || len < (int)sizeof(supernova_camera_packet_t)) {
        return;
    }

    supernova_camera_packet_t packet = {};
    memcpy(&packet, data, sizeof(packet));
    if(packet.magic != camera_packet_magic || packet.version != camera_packet_version ||
       packet.type != camera_packet_credentials) {
        return;
    }

    packet.ssid[sizeof(packet.ssid) - 1] = '\0';
    packet.password[sizeof(packet.password) - 1] = '\0';
    if(packet.ssid[0] == '\0') {
        return;
    }

    save_credentials(packet.ssid, packet.password);
}

static void ensure_espnow(void)
{
    if(espnow_ready) {
        return;
    }

    WiFi.mode(WIFI_STA);
    WiFi.setSleep(false);
    if(esp_now_init() != ESP_OK) {
        Serial.println("ESP-NOW init failed on camera");
        return;
    }

    esp_now_register_recv_cb(espnow_receive_cb);

    esp_now_peer_info_t peer = {};
    memcpy(peer.peer_addr, broadcast_mac, sizeof(broadcast_mac));
    peer.channel = 0;
    peer.encrypt = false;
    esp_err_t add_result = esp_now_add_peer(&peer);
    if(add_result != ESP_OK && add_result != ESP_ERR_ESPNOW_EXIST) {
        Serial.printf("ESP-NOW peer add failed: %d\n", add_result);
    }

    espnow_ready = true;
    Serial.println("ESP-NOW ready on ESP32-CAM");
}

static void hop_listen_channel(void)
{
    if(WiFi.status() == WL_CONNECTED || millis() - last_channel_hop_ms < 450UL) {
        return;
    }

    last_channel_hop_ms = millis();
    esp_wifi_set_promiscuous(true);
    esp_wifi_set_channel(listen_channel, WIFI_SECOND_CHAN_NONE);
    esp_wifi_set_promiscuous(false);
    listen_channel++;
    if(listen_channel > 13) {
        listen_channel = 1;
    }
}

static esp_err_t status_handler(httpd_req_t * req)
{
    char body[192];
    snprintf(body, sizeof(body),
             "{\"name\":\"SupernovaCam\",\"ip\":\"%s\",\"rssi\":%d,\"uptime\":%lu,\"camera\":%s}",
             WiFi.localIP().toString().c_str(),
             WiFi.RSSI(),
             millis() / 1000UL,
             camera_initialized ? "true" : "false");
    httpd_resp_set_type(req, "application/json");
    return httpd_resp_send(req, body, HTTPD_RESP_USE_STRLEN);
}

static esp_err_t capture_handler(httpd_req_t * req)
{
    if(!camera_initialized) {
        httpd_resp_send_500(req);
        return ESP_FAIL;
    }

    camera_fb_t * fb = NULL;
    for(uint8_t attempt = 0; attempt < 3 && fb == NULL; ++attempt) {
        fb = esp_camera_fb_get();
        if(fb == NULL) {
            delay(80);
        }
    }
    if(fb == NULL) {
        Serial.println("Camera capture failed: no frame buffer");
        httpd_resp_send_500(req);
        return ESP_FAIL;
    }

    httpd_resp_set_type(req, "image/jpeg");
    httpd_resp_set_hdr(req, "Cache-Control", "no-store");
    char len_text[16];
    snprintf(len_text, sizeof(len_text), "%u", (unsigned)fb->len);
    httpd_resp_set_hdr(req, "Content-Length", len_text);
    esp_err_t res = httpd_resp_send(req, (const char *)fb->buf, fb->len);
    esp_camera_fb_return(fb);
    return res;
}

static void * preview_alloc(size_t bytes)
{
    void * ptr = ps_malloc(bytes);
    if(ptr == NULL) {
        ptr = heap_caps_malloc(bytes, MALLOC_CAP_8BIT);
    }
    return ptr;
}

static bool ensure_preview_buffers(void)
{
    if(preview_decode_buffer == NULL) {
        preview_decode_buffer = (uint16_t *)preview_alloc((size_t)camera_capture_width *
                                                          camera_capture_height *
                                                          sizeof(uint16_t));
    }
    if(preview_output_buffer == NULL) {
        preview_output_buffer = (uint16_t *)preview_alloc((size_t)preview_width *
                                                          preview_height *
                                                          sizeof(uint16_t));
    }

    if(preview_decode_buffer == NULL || preview_output_buffer == NULL) {
        Serial.println("Camera preview buffers could not be allocated");
        return false;
    }
    return true;
}

static esp_err_t preview565_handler(httpd_req_t * req)
{
    if(!camera_initialized || !ensure_preview_buffers()) {
        httpd_resp_send_500(req);
        return ESP_FAIL;
    }

    camera_fb_t * fb = NULL;
    for(uint8_t attempt = 0; attempt < 3 && fb == NULL; ++attempt) {
        fb = esp_camera_fb_get();
        if(fb == NULL) {
            delay(80);
        }
    }
    if(fb == NULL) {
        Serial.println("Camera preview failed: no frame buffer");
        httpd_resp_send_500(req);
        return ESP_FAIL;
    }

    const bool decoded = jpg2rgb565(fb->buf,
                                    fb->len,
                                    (uint8_t *)preview_decode_buffer,
                                    JPG_SCALE_NONE);
    esp_camera_fb_return(fb);
    if(!decoded) {
        Serial.println("Camera preview JPEG decode failed");
        httpd_resp_send_500(req);
        return ESP_FAIL;
    }

    const uint16_t crop_height = 92;
    const uint16_t crop_y = (camera_capture_height - crop_height) / 2;
    for(uint16_t y = 0; y < preview_height; ++y) {
        const uint16_t src_y = crop_y + ((uint32_t)y * crop_height) / preview_height;
        const uint16_t * src_row = preview_decode_buffer + (size_t)src_y * camera_capture_width;
        uint16_t * dst_row = preview_output_buffer + (size_t)y * preview_width;
        for(uint16_t x = 0; x < preview_width; ++x) {
            const uint16_t src_x = ((uint32_t)x * camera_capture_width) / preview_width;
            dst_row[x] = src_row[src_x];
        }
    }

    char len_text[16];
    snprintf(len_text, sizeof(len_text), "%u", (unsigned)((size_t)preview_width *
                                                          preview_height *
                                                          sizeof(uint16_t)));
    httpd_resp_set_type(req, "application/octet-stream");
    httpd_resp_set_hdr(req, "Cache-Control", "no-store");
    httpd_resp_set_hdr(req, "X-Preview-Width", "260");
    httpd_resp_set_hdr(req, "X-Preview-Height", "150");
    httpd_resp_set_hdr(req, "Content-Length", len_text);
    return httpd_resp_send(req,
                           (const char *)preview_output_buffer,
                           (size_t)preview_width * preview_height * sizeof(uint16_t));
}

static esp_err_t stream_handler(httpd_req_t * req)
{
    if(!camera_initialized) {
        httpd_resp_send_500(req);
        return ESP_FAIL;
    }

    static const char * boundary = "\r\n--supernova\r\n";
    httpd_resp_set_type(req, "multipart/x-mixed-replace;boundary=supernova");
    httpd_resp_set_hdr(req, "Cache-Control", "no-store");

    while(true) {
        camera_fb_t * fb = esp_camera_fb_get();
        if(fb == NULL) {
            return ESP_FAIL;
        }

        char header[96];
        const int header_len = snprintf(header, sizeof(header),
                                        "Content-Type: image/jpeg\r\nContent-Length: %u\r\n\r\n",
                                        (unsigned)fb->len);
        esp_err_t res = httpd_resp_send_chunk(req, boundary, strlen(boundary));
        if(res == ESP_OK) {
            res = httpd_resp_send_chunk(req, header, header_len);
        }
        if(res == ESP_OK) {
            res = httpd_resp_send_chunk(req, (const char *)fb->buf, fb->len);
        }
        esp_camera_fb_return(fb);
        if(res != ESP_OK) {
            break;
        }
        delay(60);
    }

    return ESP_OK;
}

static void start_server(void)
{
    if(camera_httpd != NULL) {
        return;
    }

    httpd_config_t config = HTTPD_DEFAULT_CONFIG();
    config.server_port = 80;
    config.ctrl_port = 32768;
    config.stack_size = 6144;
    config.max_uri_handlers = 6;

    if(httpd_start(&camera_httpd, &config) != ESP_OK) {
        Serial.println("Camera HTTP server failed");
        camera_httpd = NULL;
        return;
    }

    httpd_uri_t status_uri = { .uri = "/status", .method = HTTP_GET, .handler = status_handler, .user_ctx = NULL };
    httpd_uri_t capture_uri = { .uri = "/capture", .method = HTTP_GET, .handler = capture_handler, .user_ctx = NULL };
    httpd_uri_t jpg_uri = { .uri = "/jpg", .method = HTTP_GET, .handler = capture_handler, .user_ctx = NULL };
    httpd_uri_t preview_uri = { .uri = "/preview565", .method = HTTP_GET, .handler = preview565_handler, .user_ctx = NULL };
    httpd_uri_t stream_uri = { .uri = "/stream", .method = HTTP_GET, .handler = stream_handler, .user_ctx = NULL };
    httpd_register_uri_handler(camera_httpd, &status_uri);
    httpd_register_uri_handler(camera_httpd, &capture_uri);
    httpd_register_uri_handler(camera_httpd, &jpg_uri);
    httpd_register_uri_handler(camera_httpd, &preview_uri);
    httpd_register_uri_handler(camera_httpd, &stream_uri);
    Serial.printf("Camera HTTP server ready: http://%s/status\n", WiFi.localIP().toString().c_str());
}

static bool probe_camera_sccb(void)
{
    if(last_sccb_probe_ms != 0 && millis() - last_sccb_probe_ms < 15000UL) {
        return true;
    }
    last_sccb_probe_ms = millis();

    bool found = false;
    ledcSetup(LEDC_CHANNEL_0, 10000000, 1);
    ledcAttachPin(XCLK_GPIO_NUM, LEDC_CHANNEL_0);
    ledcWrite(LEDC_CHANNEL_0, 1);
    delay(80);

    Wire.begin(SIOD_GPIO_NUM, SIOC_GPIO_NUM);
    Wire.setClock(100000);

    for(uint8_t address = 1; address < 0x78; ++address) {
        Wire.beginTransmission(address);
        if(Wire.endTransmission() == 0) {
            Serial.printf("Camera SCCB/I2C device found at 0x%02x\n", address);
            found = true;
        }
        delay(2);
    }

    Wire.end();
    ledcDetachPin(XCLK_GPIO_NUM);
    if(!found) {
        Serial.println("No camera SCCB/I2C device found on SIOD=26 SIOC=27");
    }
    return found;
}

static bool init_camera(void)
{
    pinMode(PWDN_GPIO_NUM, OUTPUT);
    digitalWrite(PWDN_GPIO_NUM, HIGH);
    delay(60);
    digitalWrite(PWDN_GPIO_NUM, LOW);
    delay(180);
    probe_camera_sccb();

    camera_config_t config = {};
    config.ledc_channel = LEDC_CHANNEL_0;
    config.ledc_timer = LEDC_TIMER_0;
    config.pin_d0 = Y2_GPIO_NUM;
    config.pin_d1 = Y3_GPIO_NUM;
    config.pin_d2 = Y4_GPIO_NUM;
    config.pin_d3 = Y5_GPIO_NUM;
    config.pin_d4 = Y6_GPIO_NUM;
    config.pin_d5 = Y7_GPIO_NUM;
    config.pin_d6 = Y8_GPIO_NUM;
    config.pin_d7 = Y9_GPIO_NUM;
    config.pin_xclk = XCLK_GPIO_NUM;
    config.pin_pclk = PCLK_GPIO_NUM;
    config.pin_vsync = VSYNC_GPIO_NUM;
    config.pin_href = HREF_GPIO_NUM;
    config.pin_sccb_sda = SIOD_GPIO_NUM;
    config.pin_sccb_scl = SIOC_GPIO_NUM;
    config.pin_pwdn = PWDN_GPIO_NUM;
    config.pin_reset = RESET_GPIO_NUM;
    config.xclk_freq_hz = 20000000;
    config.pixel_format = PIXFORMAT_JPEG;
    Serial.printf("PSRAM: %s\n", psramFound() ? "found" : "not found");
    config.frame_size = FRAMESIZE_QQVGA;
    config.jpeg_quality = 18;
    config.fb_count = 1;
    config.fb_location = psramFound() ? CAMERA_FB_IN_PSRAM : CAMERA_FB_IN_DRAM;
    config.grab_mode = CAMERA_GRAB_WHEN_EMPTY;

    esp_err_t err = esp_camera_init(&config);
    if(err != ESP_OK) {
        Serial.printf("Camera init failed at 20MHz: 0x%x, retrying 10MHz\n", err);
        esp_camera_deinit();
        digitalWrite(PWDN_GPIO_NUM, HIGH);
        delay(80);
        digitalWrite(PWDN_GPIO_NUM, LOW);
        delay(180);
        config.xclk_freq_hz = 10000000;
        err = esp_camera_init(&config);
    }
    if(err != ESP_OK) {
        Serial.printf("Camera init failed: 0x%x\n", err);
        return false;
    }

    sensor_t * sensor = esp_camera_sensor_get();
    if(sensor != NULL) {
        sensor->set_framesize(sensor, FRAMESIZE_QQVGA);
        sensor->set_quality(sensor, 18);
        sensor->set_vflip(sensor, 0);
        sensor->set_hmirror(sensor, 0);
    }

    delay(900);
    camera_fb_t * test_frame = NULL;
    for(uint8_t attempt = 0; attempt < 6 && test_frame == NULL; ++attempt) {
        test_frame = esp_camera_fb_get();
        if(test_frame == NULL) {
            delay(180);
        }
    }
    if(test_frame == NULL) {
        Serial.println("Camera init test failed: no frame");
        esp_camera_deinit();
        return false;
    }
    Serial.printf("Camera init test frame: %ux%u %u bytes\n",
                  test_frame->width,
                  test_frame->height,
                  (unsigned)test_frame->len);
    esp_camera_fb_return(test_frame);

    Serial.println("Camera sensor ready");
    return true;
}

static void connect_wifi_if_needed(void)
{
    if(saved_ssid[0] == '\0' || WiFi.status() == WL_CONNECTED) {
        return;
    }
    if(!pending_wifi_connect && millis() - last_wifi_attempt_ms < 12000UL) {
        return;
    }

    pending_wifi_connect = false;
    last_wifi_attempt_ms = millis();
    WiFi.mode(WIFI_STA);
    WiFi.setSleep(false);
    WiFi.begin(saved_ssid, saved_password);
    Serial.printf("Connecting ESP32-CAM to WiFi: %s\n", saved_ssid);
}

static void announce_camera(void)
{
    if(!espnow_ready || WiFi.status() != WL_CONNECTED || millis() - last_announce_ms < 2000UL) {
        return;
    }

    last_announce_ms = millis();
    supernova_camera_packet_t packet = {};
    packet.magic = camera_packet_magic;
    packet.version = camera_packet_version;
    packet.type = camera_packet_announce;
    packet.port = 80;
    WiFi.localIP().toString().toCharArray(packet.ip, sizeof(packet.ip));
    esp_now_send(broadcast_mac, (const uint8_t *)&packet, sizeof(packet));
}

void setup(void)
{
    Serial.begin(115200);
    Serial.setDebugOutput(true);
    delay(500);
    Serial.println();
    Serial.println("Starting Supernova ESP32-CAM");
    pinMode(FLASH_GPIO_NUM, OUTPUT);
    digitalWrite(FLASH_GPIO_NUM, LOW);

    WiFi.mode(WIFI_STA);
    WiFi.setSleep(false);
    ensure_espnow();
    load_credentials();
    if(saved_ssid[0] != '\0') {
        pending_wifi_connect = true;
    }
}

void loop(void)
{
    if(millis() - last_loop_log_ms > 5000UL) {
        last_loop_log_ms = millis();
        Serial.printf("Loop wifi=%d ssid=%s pending=%d camera=%d channel=%u\n",
                      WiFi.status(),
                      saved_ssid,
                      pending_wifi_connect ? 1 : 0,
                      camera_initialized ? 1 : 0,
                      listen_channel);
    }
    ensure_espnow();
    save_credentials_to_flash();
    connect_wifi_if_needed();
    hop_listen_channel();
    if(WiFi.status() == WL_CONNECTED) {
        start_server();
        if(!camera_initialized && millis() - last_camera_init_attempt_ms > 3000UL) {
            last_camera_init_attempt_ms = millis();
            camera_initialized = init_camera();
        }
        if(camera_initialized) {
            announce_camera();
        }
    }
    delay(20);
}

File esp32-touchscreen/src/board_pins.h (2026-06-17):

#ifndef BOARD_PINS_H
#define BOARD_PINS_H

/* LCDWiki/diymore 4.0inch ESP32-32E Display, touch SKU E32R40T. */
#define LCD_HOST_SPI HSPI_HOST

#define LCD_PIN_CS 15
#define LCD_PIN_DC 2
#define LCD_PIN_SCLK 14
#define LCD_PIN_MOSI 13
#define LCD_PIN_MISO 12
#define LCD_PIN_RST -1
#define LCD_PIN_BL 27

#define TOUCH_PIN_CS 33
#define TOUCH_PIN_IRQ 36

#define SD_PIN_CS 5
#define SD_PIN_SCLK 18
#define SD_PIN_MOSI 23
#define SD_PIN_MISO 19

/* Optional on-board peripherals, not used by the first UI version. */
#define RGB_LED_RED 22
#define RGB_LED_GREEN 16
#define RGB_LED_BLUE 17
#define BATTERY_ADC_PIN 34
#define AUDIO_ENABLE_PIN 4
#define AUDIO_DAC_PIN 26

#endif /* BOARD_PINS_H */

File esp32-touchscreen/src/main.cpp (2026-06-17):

#include <Arduino.h>
#include <SPI.h>
#include <esp_heap_caps.h>
#include <lvgl.h>

#include "board_pins.h"
#include "supernova_camera.h"
#include "supernova_mqtt.h"
#include "supernova_state.h"
#include "ui_boot.h"
#include "ui_config.h"

#if 0

static SPIClass test_spi(HSPI);
static const SPISettings test_spi_settings(1000000, MSBFIRST, SPI_MODE0);

static void test_select(void)
{
    digitalWrite(LCD_PIN_CS, LOW);
}

static void test_deselect(void)
{
    digitalWrite(LCD_PIN_CS, HIGH);
}

static void test_cmd(uint8_t cmd)
{
    digitalWrite(LCD_PIN_DC, LOW);
    test_select();
    test_spi.transfer(cmd);
    test_deselect();
}

static void test_data(uint8_t data)
{
    digitalWrite(LCD_PIN_DC, HIGH);
    test_select();
    test_spi.transfer(data);
    test_deselect();
}

static void test_data16(uint16_t data)
{
    test_spi.transfer(data >> 8);
    test_spi.transfer(data & 0xFF);
}

static void test_set_window(uint16_t x0, uint16_t y0, uint16_t x1, uint16_t y1)
{
    test_cmd(0x2A);
    digitalWrite(LCD_PIN_DC, HIGH);
    test_select();
    test_data16(x0);
    test_data16(x1);
    test_deselect();

    test_cmd(0x2B);
    digitalWrite(LCD_PIN_DC, HIGH);
    test_select();
    test_data16(y0);
    test_data16(y1);
    test_deselect();

    test_cmd(0x2C);
}

static void test_fill(uint16_t w, uint16_t h, uint16_t color)
{
    test_set_window(0, 0, w - 1, h - 1);
    digitalWrite(LCD_PIN_DC, HIGH);
    test_select();
    for(uint32_t i = 0; i < (uint32_t)w * h; ++i) {
        test_data16(color);
    }
    test_deselect();
}

static void test_init_st7796s(void)
{
    test_cmd(0x11);
    delay(120);

    test_cmd(0x36);
    test_data(0x48);
    test_cmd(0x3A);
    test_data(0x55);
    test_cmd(0xF0);
    test_data(0xC3);
    test_cmd(0xF0);
    test_data(0x96);
    test_cmd(0xB4);
    test_data(0x01);
    test_cmd(0xB7);
    test_data(0xC6);
    test_cmd(0xC0);
    test_data(0x80);
    test_data(0x45);
    test_cmd(0xC1);
    test_data(0x13);
    test_cmd(0xC2);
    test_data(0xA7);
    test_cmd(0xC5);
    test_data(0x20);
    test_cmd(0xE8);
    const uint8_t display_output[] = {0x40, 0x8A, 0x00, 0x00, 0x29, 0x19, 0xA5, 0x33};
    for(uint8_t value : display_output) {
        test_data(value);
    }
    test_cmd(0xE0);
    const uint8_t gamma_pos[] = {0xD0, 0x08, 0x0F, 0x06, 0x06, 0x33, 0x30,
                                 0x33, 0x47, 0x17, 0x13, 0x13, 0x2B, 0x31};
    for(uint8_t value : gamma_pos) {
        test_data(value);
    }
    test_cmd(0xE1);
    const uint8_t gamma_neg[] = {0xD0, 0x0A, 0x11, 0x0B, 0x09, 0x07, 0x2F,
                                 0x33, 0x47, 0x38, 0x15, 0x16, 0x2C, 0x32};
    for(uint8_t value : gamma_neg) {
        test_data(value);
    }
    test_cmd(0xF0);
    test_data(0x3C);
    test_cmd(0xF0);
    test_data(0x69);
    delay(120);
    test_cmd(0x29);
    delay(120);
}

void setup(void)
{
    Serial.begin(115200);
    delay(300);
    Serial.println();
    Serial.println("Starting ST7796S landscape diagnostic");

    pinMode(LCD_PIN_CS, OUTPUT);
    pinMode(LCD_PIN_DC, OUTPUT);
    pinMode(LCD_PIN_BL, OUTPUT);
    pinMode(TOUCH_PIN_CS, OUTPUT);
    pinMode(SD_PIN_CS, OUTPUT);

    digitalWrite(LCD_PIN_CS, HIGH);
    digitalWrite(TOUCH_PIN_CS, HIGH);
    digitalWrite(SD_PIN_CS, HIGH);
    digitalWrite(LCD_PIN_DC, HIGH);
    digitalWrite(LCD_PIN_BL, HIGH);

    test_spi.begin(LCD_PIN_SCLK, LCD_PIN_MISO, LCD_PIN_MOSI, LCD_PIN_CS);
    test_spi.beginTransaction(test_spi_settings);
    test_init_st7796s();
}

void loop(void)
{
    Serial.println("portrait red 320x480");
    test_cmd(0x36);
    test_data(0x48);
    test_fill(320, 480, 0xF800);
    delay(1500);

    Serial.println("landscape green 480x320 madctl 0x28");
    test_cmd(0x36);
    test_data(0x28);
    test_fill(480, 320, 0x07E0);
    delay(1500);

    Serial.println("landscape blue 480x320 madctl 0xE8");
    test_cmd(0x36);
    test_data(0xE8);
    test_fill(480, 320, 0x001F);
    delay(1500);
}

#else

SPIClass display_spi(HSPI);
static const uint32_t lcd_spi_frequency = 40000000;
static const uint16_t lvgl_buffer_rows = 80;
static const SPISettings lcd_spi_settings(lcd_spi_frequency, MSBFIRST, SPI_MODE0);
static const SPISettings touch_spi_settings(1000000, MSBFIRST, SPI_MODE0);

static lv_display_t * lvgl_display = NULL;
static lv_indev_t * lvgl_touch = NULL;
static lv_color_t * draw_buffer = NULL;
static uint16_t active_lvgl_buffer_rows = 0;
static uint32_t last_tick_ms = 0;
static lv_point_t last_touch_point = {UI_DISPLAY_WIDTH / 2, UI_DISPLAY_HEIGHT / 2};
static uint32_t last_touch_log_ms = 0;
static uint32_t touch_wake_ignore_until_ms = 0;

static void lcd_begin_write(void)
{
    display_spi.beginTransaction(lcd_spi_settings);
    digitalWrite(LCD_PIN_CS, LOW);
}

static void lcd_end_write(void)
{
    digitalWrite(LCD_PIN_CS, HIGH);
    display_spi.endTransaction();
}

static void lcd_write_command_inline(uint8_t cmd)
{
    digitalWrite(LCD_PIN_DC, LOW);
    display_spi.transfer(cmd);
    digitalWrite(LCD_PIN_DC, HIGH);
}

static void lcd_write_data_inline(uint8_t data)
{
    display_spi.transfer(data);
}

static void lcd_write_data16_inline(uint16_t data)
{
    display_spi.transfer(data >> 8);
    display_spi.transfer(data & 0xFF);
}

static void lcd_write_command(uint8_t cmd)
{
    lcd_begin_write();
    lcd_write_command_inline(cmd);
    lcd_end_write();
}

static void lcd_write_command_data(uint8_t cmd, const uint8_t * data, size_t length)
{
    lcd_begin_write();
    lcd_write_command_inline(cmd);
    for(size_t i = 0; i < length; ++i) {
        lcd_write_data_inline(data[i]);
    }
    lcd_end_write();
}

static void lcd_set_window_inline(uint16_t x0, uint16_t y0, uint16_t x1, uint16_t y1)
{
    lcd_write_command_inline(0x2A);
    lcd_write_data16_inline(x0);
    lcd_write_data16_inline(x1);

    lcd_write_command_inline(0x2B);
    lcd_write_data16_inline(y0);
    lcd_write_data16_inline(y1);

    lcd_write_command_inline(0x2C);
}

static void lcd_fill_screen(uint16_t color)
{
    lcd_begin_write();
    lcd_set_window_inline(0, 0, UI_DISPLAY_WIDTH - 1, UI_DISPLAY_HEIGHT - 1);
    for(uint32_t i = 0; i < (uint32_t)UI_DISPLAY_WIDTH * UI_DISPLAY_HEIGHT; ++i) {
        lcd_write_data16_inline(color);
    }
    lcd_end_write();
}
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

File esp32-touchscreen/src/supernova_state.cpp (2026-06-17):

#include "supernova_state.h"

#include "supernova_devices.h"

#if defined(ARDUINO)
#include <Arduino.h>
#include <ArduinoJson.h>
#include <HTTPClient.h>
#include <Preferences.h>
#include <WiFiClientSecure.h>
#include <WiFi.h>
#include <time.h>
#endif

static const char * songs[] = {
    "Supernova Intro.wav",
    "Orbit Drive.mp3",
    "Nebula Pulse.mp3",
    "Mission Control.wav",
};

static const char * languages[] = {
    "English",
    "Deutsch",
};

static const char * old_default_wifi_ssid = "CHANGE_ME_OLD_SSID";
static const char * default_wifi_ssid = "CHANGE_ME_WIFI_SSID";
static const char * default_wifi_password = "CHANGE_ME_WIFI_PASSWORD";
static const char * prefs_namespace = "supernova";
static const char * prefs_language_key = "lang";
static const char * prefs_brightness_key = "bright";
static const char * prefs_wifi_ssid_key = "wifi_ssid";
static const char * prefs_wifi_password_key = "wifi_pass";
static const char * prefs_wifi_revision_key = "wifi_rev";
static const uint8_t current_wifi_revision = 2;
static const char * vienna_tz = "CET-1CEST,M3.5.0/2,M10.5.0/3";
static const char * weather_url =
    "https://api.open-meteo.com/v1/forecast?"
    "latitude=48.2085&longitude=16.3721"
    "&current=temperature_2m,weather_code"
    "&daily=weather_code,temperature_2m_max,temperature_2m_min"
    "&timezone=Europe%2FVienna&forecast_days=4";

static int8_t current_song = -1;
static bool music_playing = false;
static uint8_t volume_value = 55;
static uint8_t brightness_value = 85;
static supernova_led_mode_t led_mode_value = SUPERNOVA_LED_NOVA_PULSE;
static uint8_t language_index_value = 0;
static char last_wifi_ssid[33] = "";
static char pending_wifi_ssid[33] = "";
static char pending_wifi_password[65] = "";
static bool wifi_credentials_save_pending = false;
static bool time_configured = false;
static bool time_synced_value = false;
static bool screen_sleeping_value = false;
static bool screen_dimmed_value = false;
static uint32_t last_screen_activity_ms = 0;
static uint32_t last_time_sync_attempt_ms = 0;
static uint32_t last_weather_attempt_ms = 0;
static uint32_t last_weather_success_ms = 0;
static supernova_weather_t weather_value = {};
#if defined(ARDUINO)
static TaskHandle_t weather_task_handle = NULL;
#endif

static const uint32_t screen_dim_after_ms = 30000UL;
static const uint32_t screen_sleep_after_ms = 60000UL;
static const uint8_t screen_dim_brightness = 1;

static uint8_t language_count(void)
{
    return (uint8_t)(sizeof(languages) / sizeof(languages[0]));
}

static uint8_t load_language_index(void)
{
#if defined(ARDUINO)
    Preferences prefs;
    if(prefs.begin(prefs_namespace, true)) {
        uint8_t saved = prefs.getUChar(prefs_language_key, 0);
        prefs.end();
        if(saved < language_count()) {
            return saved;
        }
    }
#endif

    return 0;
}

static void save_language_index(uint8_t index)
{
#if defined(ARDUINO)
    Preferences prefs;
    if(prefs.begin(prefs_namespace, false)) {
        prefs.putUChar(prefs_language_key, index);
        prefs.end();
    }
#else
    (void)index;
#endif
}

static uint8_t load_brightness(void)
{
#if defined(ARDUINO)
    Preferences prefs;
    if(prefs.begin(prefs_namespace, true)) {
        uint8_t saved = prefs.getUChar(prefs_brightness_key, brightness_value);
        prefs.end();
        if(saved <= 100) {
            return saved;
        }
    }
#endif

    return brightness_value;
}

static void save_brightness(uint8_t brightness)
{
#if defined(ARDUINO)
    Preferences prefs;
    if(prefs.begin(prefs_namespace, false)) {
        prefs.putUChar(prefs_brightness_key, brightness);
        prefs.end();
    }
#else
    (void)brightness;
#endif
}

static void load_wifi_credentials(char * ssid, size_t ssid_size, char * password, size_t password_size)
{
    if(ssid_size > 0) {
        ssid[0] = '\0';
    }
    if(password_size > 0) {
        password[0] = '\0';
    }

#if defined(ARDUINO)
    Preferences prefs;
    if(prefs.begin(prefs_namespace, true)) {
        String saved_ssid = prefs.getString(prefs_wifi_ssid_key, "");
        String saved_password = prefs.getString(prefs_wifi_password_key, "");
        uint8_t saved_revision = prefs.getUChar(prefs_wifi_revision_key, 0);
        prefs.end();

        if(saved_ssid.length() > 0 && saved_ssid != old_default_wifi_ssid &&
           saved_revision == current_wifi_revision) {
            saved_ssid.toCharArray(ssid, ssid_size);
            saved_password.toCharArray(password, password_size);
            return;
        }
    }
#endif

    strncpy(ssid, default_wifi_ssid, ssid_size - 1);
    ssid[ssid_size - 1] = '\0';
    strncpy(password, default_wifi_password, password_size - 1);
    password[password_size - 1] = '\0';
}

static void save_wifi_credentials(const char * ssid, const char * password)
{
#if defined(ARDUINO)
    Preferences prefs;
    if(prefs.begin(prefs_namespace, false)) {
        prefs.putString(prefs_wifi_ssid_key, ssid == NULL ? "" : ssid);
        prefs.putString(prefs_wifi_password_key, password == NULL ? "" : password);
        prefs.putUChar(prefs_wifi_revision_key, current_wifi_revision);
        prefs.end();
        Serial.printf("Saved WiFi credentials for SSID: %s\n", ssid == NULL ? "" : ssid);
    }
#else
    (void)ssid;
    (void)password;
#endif
}

static int16_t celsius_x10(float value)
{
    return (int16_t)(value * 10.0f + (value >= 0.0f ? 0.5f : -0.5f));
}
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
